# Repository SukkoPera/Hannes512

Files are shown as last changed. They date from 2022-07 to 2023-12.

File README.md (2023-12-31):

# Hannes512
Hannes512 is an Open Hardware internal 512 kB RAM Expansion board for the Commodore 16.

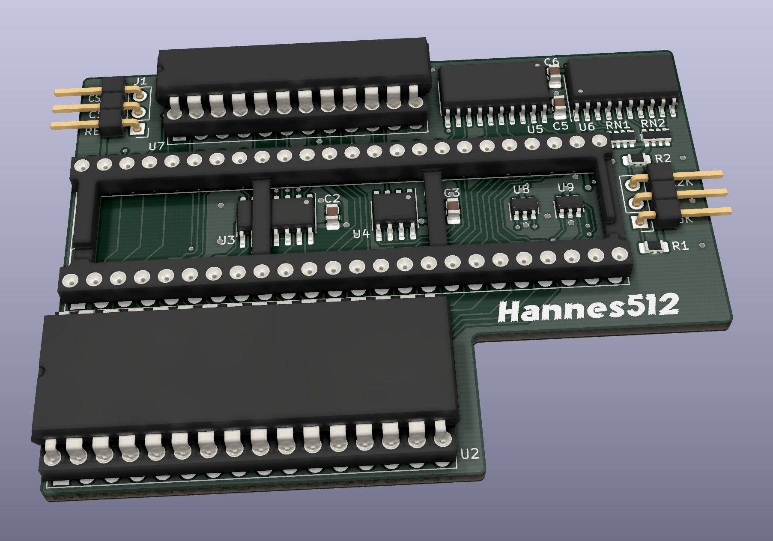
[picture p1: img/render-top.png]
Board


## Summary
While making [Hannes256](https://github.com/SukkoPera/Hannes256) two shortcomings became apparent:
* The RAM chips needed to be recovered from old equipment or bought second-hand
* The power draw was probably pretty significant (although I never measured it)

It was pretty obvious that switching to a modern SRAM would alleviate both issues, so I went looking for modern chips I could use and the Alliance AS6C4008 turned out to be a perfect match. Besides, it is 512 kB so I even went beyond the original goals and made all of that available to the C16 (even though that can create incompatibilities, see below).

## Design and Assembly Notes
This board is basically a variant of [Hannes256](https://github.com/SukkoPera/Hannes256#design-and-assembly-notes), so most of what you can read on that page also applies to this board.

One exception is that I reintroduced the ESD protection diodes for the TED that were featured in [Fixteen](https://github.com/SukkoPera/Fixteen). They are U8 and U9 and they are optional.

### RAM Compatibility
Both AS6C4008-55PCN and -55PIN have been tested and work fine. I don't know about any other chips, but it's possible that other SRAMs will work.

AS6C4008 chips can either be bought new from electronic distributors or (probably-) used from AliExpress. I have bought a few of the latter and they were all working correctly.

## Installation
See [Hannes256](https://github.com/SukkoPera/Hannes256#installation).

## Technical Notes
While the mechanism originally devised by Hannes/Solder for 256 kB memory expansion can easily be extended to 512 kB and even 1 MB expansions, it requires that software programmers behave correctly and consider the *default bank* to be bank 15. Unfortunately, some of the software requiring 256 kB that already exists was written with the assumption that no expansion larger than 256 kB would ever surface and sets bits 2/3 of the expansion control register to 0 when wanting to switch to the default bank.

This problem affects [Dream World](img/dreamworld_fd16_startup.png) and even the modern-era [Lykia](img/lykia_fd16_startup.png), for instance. The only real solution is to patch the software, but until someone does that, another option is to just limit memory expansions to 256 kB. After all, there is no software (... yet!) that needs more than that, so it currently looks like an acceptable compromise.

The great news is that this is rather easy to do in Hannes512, you just need to program the GAL with a different file. The [gal directory](gal/) contains a number of different JED files:
* **Hannes512_GAL2x.jed**: These files provide the full 512 kB.
* **Hanns512_G2x256.jed**: These files are limited to 256 kB and are the **recommended ones** to be used at the time being.
* **Hanns512_G2xH37.jed**: These files feature a hack that tries to provide more than 256 kB of memory while making banks 3 and 7 the same bank; it's a temporary hack I made mainly for myself, so please disregard it.

Feel free to open an issue if you have some suggestions on this topic.

## Testing
See [Hannes256](https://github.com/SukkoPera/Hannes256#testing).

## Programming
See [Hannes256](https://github.com/SukkoPera/Hannes256#programming), but keep in mind what is said in the *Technical Notes* above.

## Releases
If you want to get this board produced, you are recommended to get [the latest release](https://github.com/SukkoPera/Hannes512/releases) rather than the current git version, as the latter might be under development and is not guaranteed to be working.

Every release is accompanied by its Bill Of Materials (BOM) file and any relevant notes about it, which you are recommended to read carefully.

## License
The Hannes512 documentation, including the design itself, is copyright &copy; SukkoPera 2022-2023 and is licensed under the [Creative Commons Attribution-NonCommercial-ShareAlike 4.0 International License](https://creativecommons.org/licenses/by-nc-sa/4.0/).

This documentation is distributed *as is* and WITHOUT ANY EXPRESS OR IMPLIED WARRANTIES whatsoever with respect to its functionality, operability or use, including, without limitation, any implied warranties OF MERCHANTABILITY, SATISFACTORY QUALITY, FITNESS FOR A PARTICULAR PURPOSE or infringement. We expressly disclaim any liability whatsoever for any direct, indirect, consequential, incidental or special damages, including, without limitation, lost revenues, lost profits, losses resulting from business interruption or loss of data, regardless of the form of action or legal theory under which the liability may be asserted, even if advised of the possibility or likelihood of such damages.

## Support the Project
If you want to get some boards manufactured, you can get them from PCBWay through this link:

PCB from PCBWay (https://www.pcbway.com/project/shareproject/Hannes512_512_kB_RAM_Expansion_for_the_Commodore_16_4_e876fa91.html)

You get my gratitude and cheap, professionally-made and good quality PCBs, I get some credit that will help with this and [other projects](https://www.pcbway.com/project/member/?bmbno=72D33927-5EF6-42). You won't even have to worry about the various PCB options, it's all pre-configured for you!

Also, if you still have to register, [you can use this link](https://www.pcbway.com/setinvite.aspx?inviteid=41100) to get some bonus initial credit (and yield me some more).

You can also buy me a coffee if you want:

<a href='https://ko-fi.com/L3L0U18L' target='_blank'>Buy Me a Coffee at ko-fi.com</a>

## Thanks
* Hannes and Solder for the original design and documentation.
* eslapion for the SRAM enable circuit, saving me endless hours of debugging.
* Levente Hársfalvi (TLC) for plenty of help, in particular with the MOS 6529 replacement circuit.
* siz for the memory test utility.
* Alit Design for the [Crotah font](https://www.fontspace.com/crotah-font-f86873) used for the logo.

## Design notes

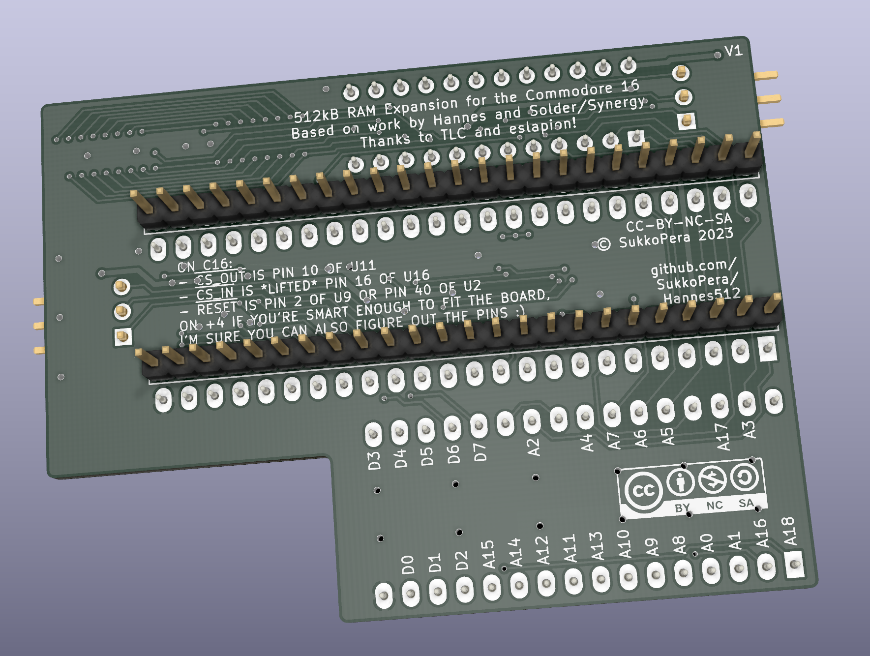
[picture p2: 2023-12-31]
img/render-bottom.png

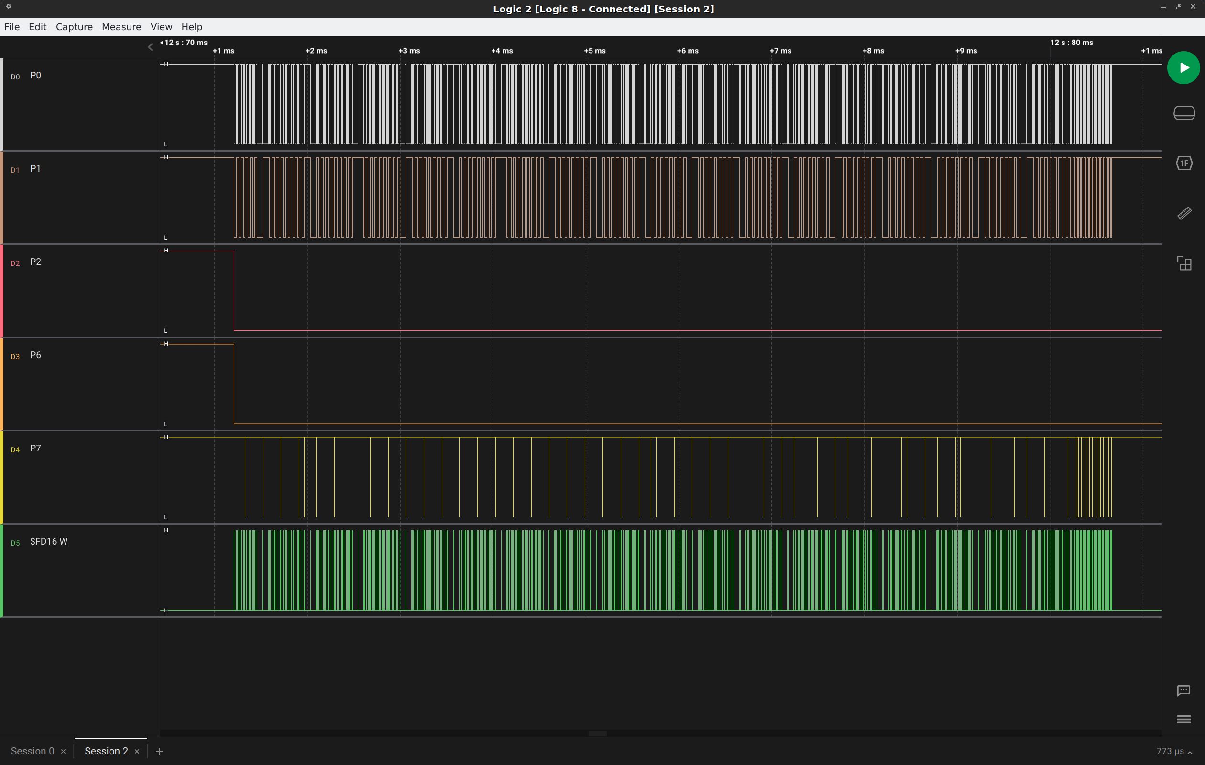
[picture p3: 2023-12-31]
doc/dreamworld_fd16_startup.png

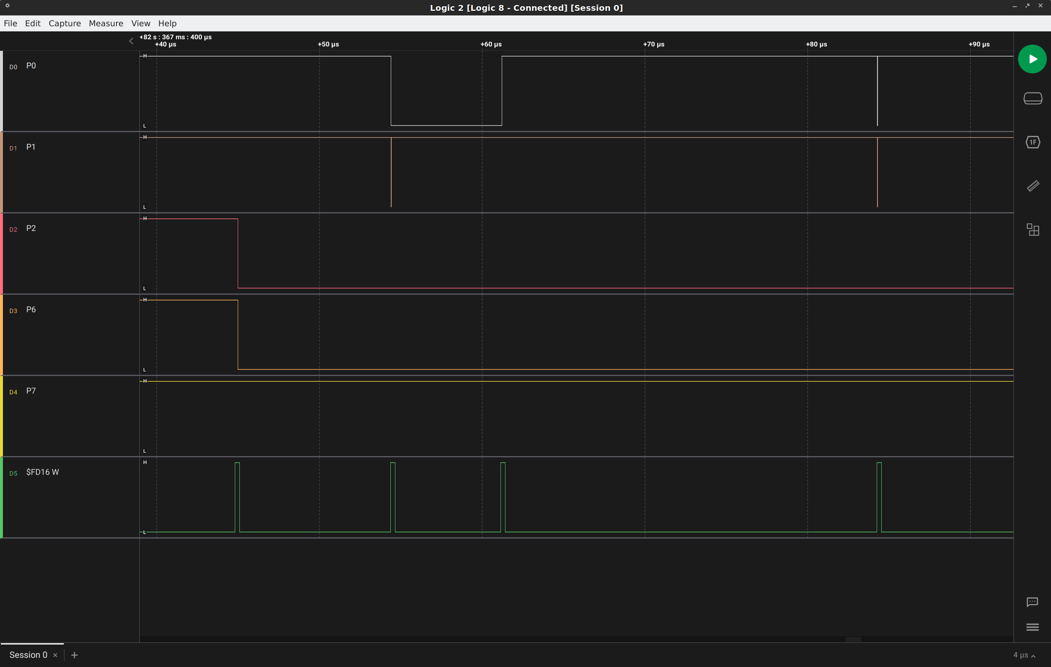
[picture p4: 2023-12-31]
doc/lykia_fd16_startup.png

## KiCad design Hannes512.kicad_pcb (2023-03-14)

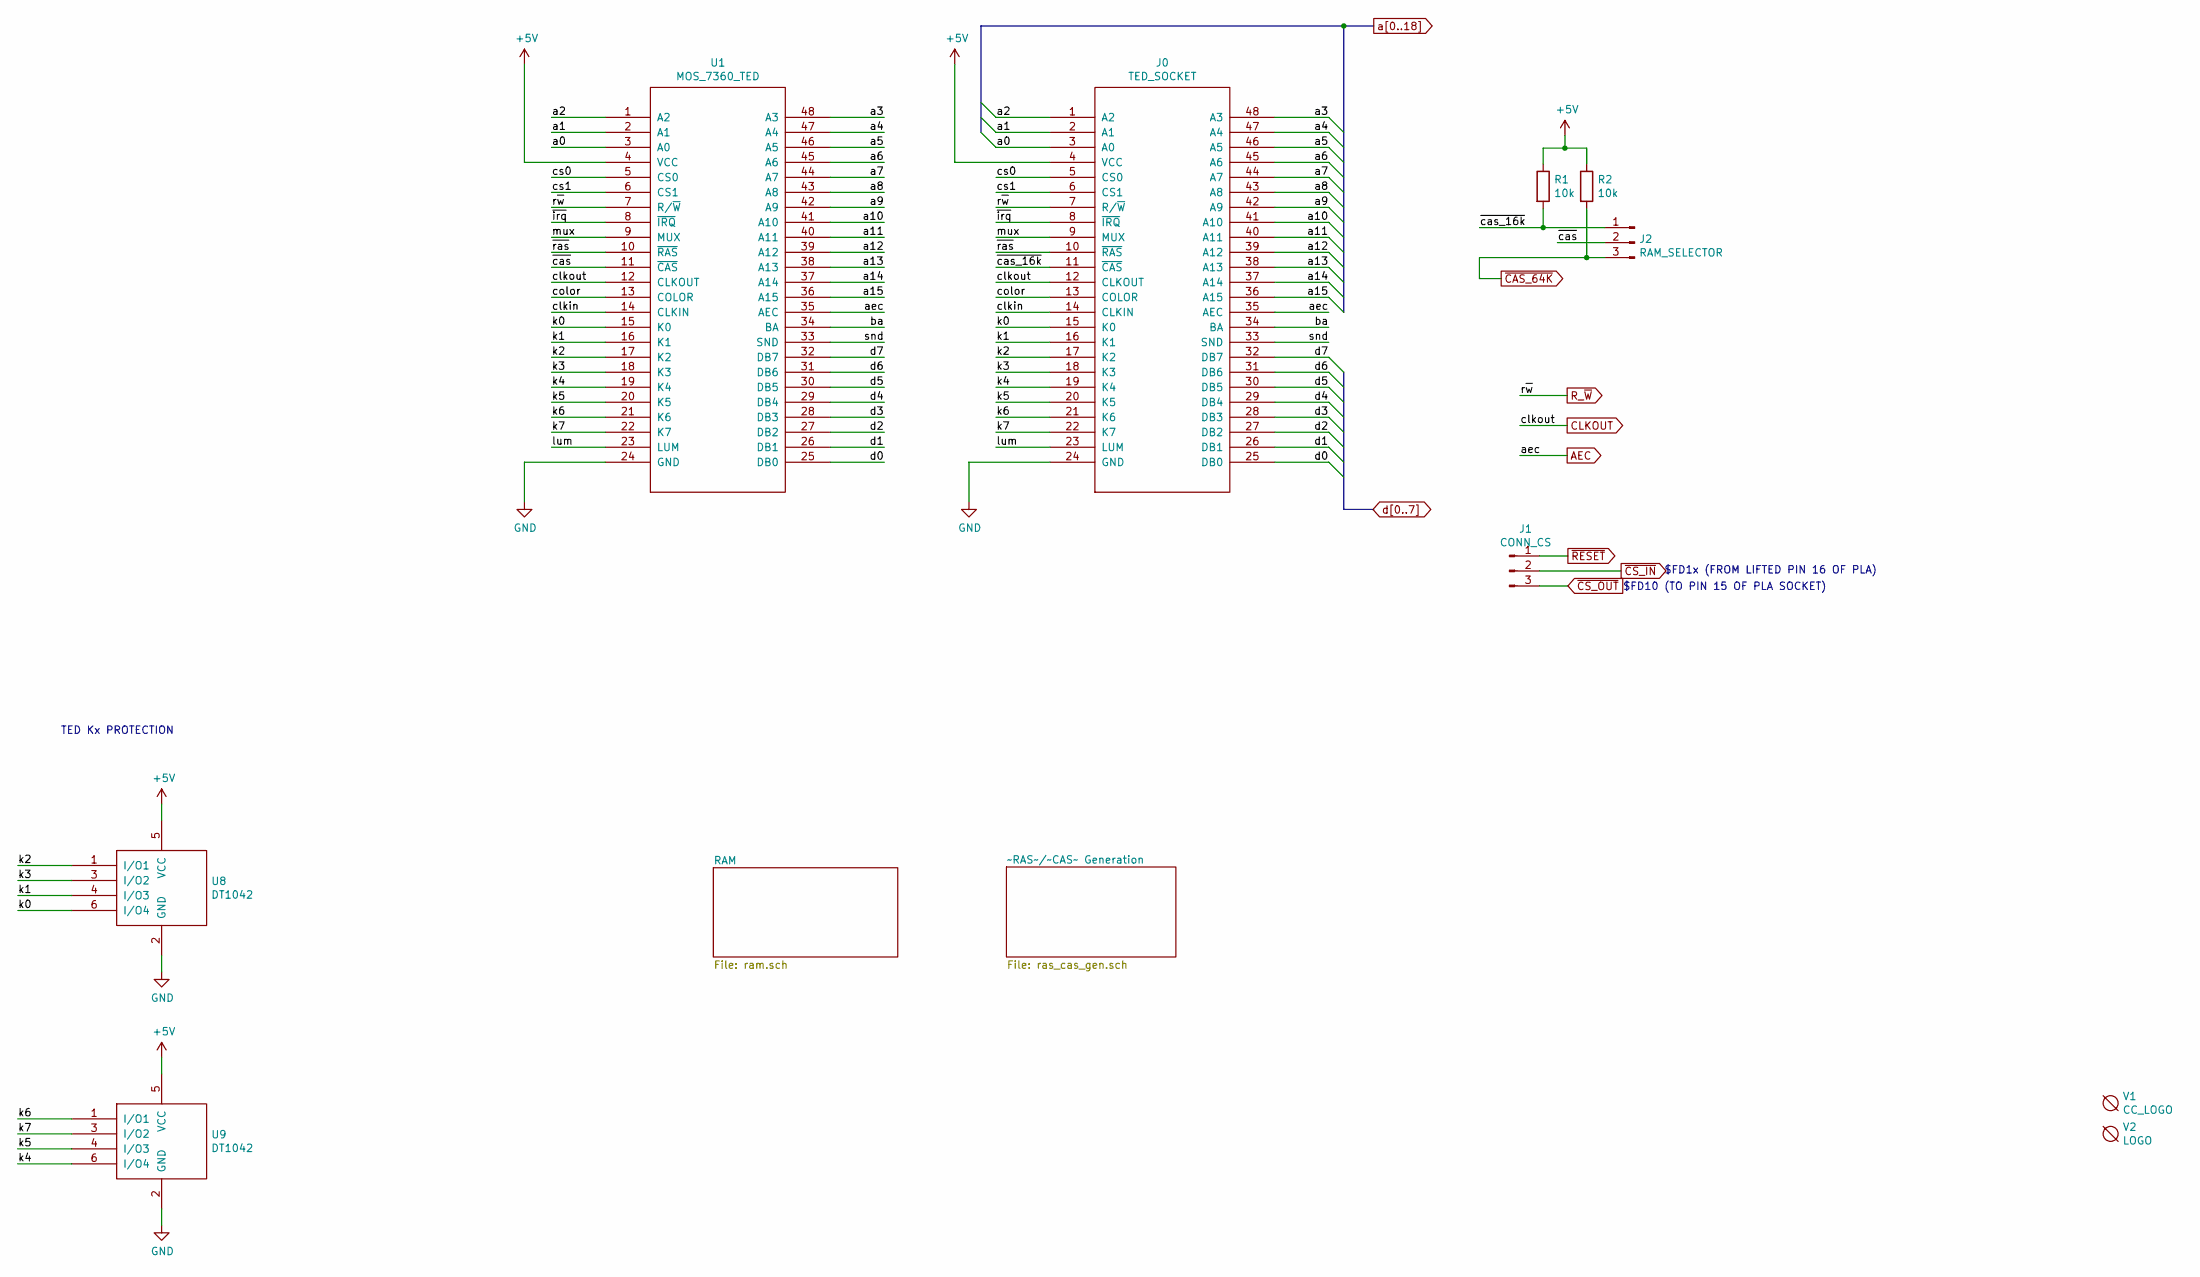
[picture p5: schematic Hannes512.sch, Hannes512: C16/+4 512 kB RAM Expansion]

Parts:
J0: TED_SOCKET; DIP-48_W15.24mm_LongPads_ModSilkS
J1: CONN_CS; PinHeader_1x03_P2.54mm_Vertical
J2: RAM_SELECTOR; PinHeader_1x03_P2.54mm_Vertical
R1, R2: 10k; R_0805_2012Metric_Pad1.20x1.40mm_HandSolder
U1: MOS_7360_TED; DIP-48_W15.24mm_Socket_LongPads
U8, U9: DT1042; TSOP-6_1.65x3.05mm_P0.95mm
V1: CC_LOGO; cc_by_nc_sa
V2: LOGO; logo

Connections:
+5V: J0.4 (VCC), R1.1, R2.1, U1.4 (VCC), U8.5 (VCC), U9.5 (VCC); also elsewhere on the board
/ba: J0.34 (BA), U1.34 (BA)
/clkin: J0.14 (CLKIN), U1.14 (CLKIN)
/color: J0.13 (COLOR), U1.13 (COLOR)
/cs0: J0.5 (CS0), U1.5 (CS0)
/cs1: J0.6 (CS1), U1.6 (CS1)
/k0: J0.15 (K0), U1.15 (K0), U8.6 (I/O4)
/k1: J0.16 (K1), U1.16 (K1), U8.4 (I/O3)
/k2: J0.17 (K2), U1.17 (K2), U8.1 (I/O1)
/k3: J0.18 (K3), U1.18 (K3), U8.3 (I/O2)
/k4: J0.19 (K4), U1.19 (K4), U9.6 (I/O4)
/k5: J0.20 (K5), U1.20 (K5), U9.4 (I/O3)
/k6: J0.21 (K6), U1.21 (K6), U9.1 (I/O1)
/k7: J0.22 (K7), U1.22 (K7), U9.3 (I/O2)
/lum: J0.23 (LUM), U1.23 (LUM)
/mux: J0.9 (MUX), U1.9 (MUX)
/snd: J0.33 (SND), U1.33 (SND)
/~cas: J2.2, U1.11 (~CAS)
/~cas_16k: J0.11 (~CAS), J2.1, R1.2
/~irq: J0.8 (~IRQ), U1.8 (~IRQ)
/~ras: J0.10 (~RAS), U1.10 (~RAS)
AEC: J0.35 (AEC), U1.35 (AEC); also elsewhere on the board
CLKOUT: J0.12 (CLKOUT), U1.12 (CLKOUT); also elsewhere on the board
GND: J0.24 (GND), U1.24 (GND), U8.2 (GND), U9.2 (GND); also elsewhere on the board
R_~W: J0.7 (R/~W), U1.7 (R/~W); also elsewhere on the board
a0: J0.3 (A0), U1.3 (A0); also elsewhere on the board
a1: J0.2 (A1), U1.2 (A1); also elsewhere on the board
a2: J0.1 (A2), U1.1 (A2); also elsewhere on the board
a3: J0.48 (A3), U1.48 (A3); also elsewhere on the board
a4: J0.47 (A4), U1.47 (A4); also elsewhere on the board
a5: J0.46 (A5), U1.46 (A5); also elsewhere on the board
a6: J0.45 (A6), U1.45 (A6); also elsewhere on the board
a7: J0.44 (A7), U1.44 (A7); also elsewhere on the board
a8: J0.43 (A8), U1.43 (A8); also elsewhere on the board
a9: J0.42 (A9), U1.42 (A9); also elsewhere on the board
a10: J0.41 (A10), U1.41 (A10); also elsewhere on the board
a11: J0.40 (A11), U1.40 (A11); also elsewhere on the board
a12: J0.39 (A12), U1.39 (A12); also elsewhere on the board
a13: J0.38 (A13), U1.38 (A13); also elsewhere on the board
a14: J0.37 (A14), U1.37 (A14); also elsewhere on the board
a15: J0.36 (A15), U1.36 (A15); also elsewhere on the board
d0: J0.25 (DB0), U1.25 (DB0); also elsewhere on the board
d1: J0.26 (DB1), U1.26 (DB1); also elsewhere on the board
d2: J0.27 (DB2), U1.27 (DB2); also elsewhere on the board
d3: J0.28 (DB3), U1.28 (DB3); also elsewhere on the board
d4: J0.29 (DB4), U1.29 (DB4); also elsewhere on the board
d5: J0.30 (DB5), U1.30 (DB5); also elsewhere on the board
d6: J0.31 (DB6), U1.31 (DB6); also elsewhere on the board
d7: J0.32 (DB7), U1.32 (DB7); also elsewhere on the board
~CAS_64K: J2.3, R2.2; also elsewhere on the board
~CS_IN: J1.2; also elsewhere on the board
~CS_OUT: J1.3; also elsewhere on the board
~RESET: J1.1; also elsewhere on the board

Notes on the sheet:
$FD1x (FROM LIFTED PIN 16 OF PLA)
$FD10 (TO PIN 15 OF PLA SOCKET)
TED Kx PROTECTION

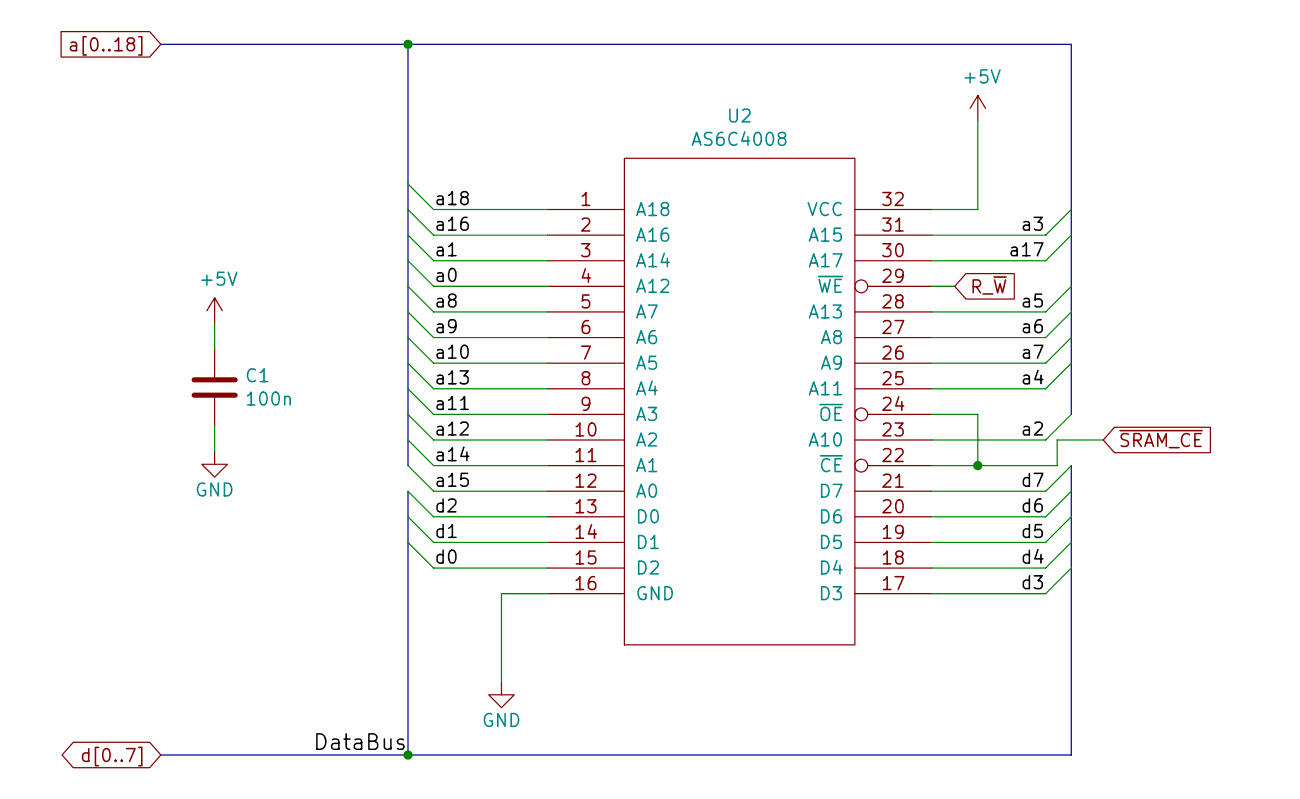
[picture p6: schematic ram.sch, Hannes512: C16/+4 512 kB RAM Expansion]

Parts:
C1: 100n; C_0805_2012Metric_Pad1.18x1.45mm_HandSolder
U2: AS6C4008; DIP-32_W15.24mm_Socket_LongPads

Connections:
+5V: C1.1, U2.32 (VCC); also elsewhere on the board
GND: C1.2, U2.16 (GND); also elsewhere on the board
R_~W: U2.29 (~WE); also elsewhere on the board
a0: U2.4 (A12); also elsewhere on the board
a1: U2.3 (A14); also elsewhere on the board
a2: U2.23 (A10); also elsewhere on the board
a3: U2.31 (A15); also elsewhere on the board
a4: U2.25 (A11); also elsewhere on the board
a5: U2.28 (A13); also elsewhere on the board
a6: U2.27 (A8); also elsewhere on the board
a7: U2.26 (A9); also elsewhere on the board
a8: U2.5 (A7); also elsewhere on the board
a9: U2.6 (A6); also elsewhere on the board
a10: U2.7 (A5); also elsewhere on the board
a11: U2.9 (A3); also elsewhere on the board
a12: U2.10 (A2); also elsewhere on the board
a13: U2.8 (A4); also elsewhere on the board
a14: U2.11 (A1); also elsewhere on the board
a15: U2.12 (A0); also elsewhere on the board
a16: U2.2 (A16); also elsewhere on the board
a17: U2.30 (A17); also elsewhere on the board
a18: U2.1 (A18); also elsewhere on the board
d0: U2.15 (D2); also elsewhere on the board
d1: U2.14 (D1); also elsewhere on the board
d2: U2.13 (D0); also elsewhere on the board
d3: U2.17 (D3); also elsewhere on the board
d4: U2.18 (D4); also elsewhere on the board
d5: U2.19 (D5); also elsewhere on the board
d6: U2.20 (D6); also elsewhere on the board
d7: U2.21 (D7); also elsewhere on the board
~SRAM_CE: U2.22 (~CE), U2.24 (~OE); also elsewhere on the board

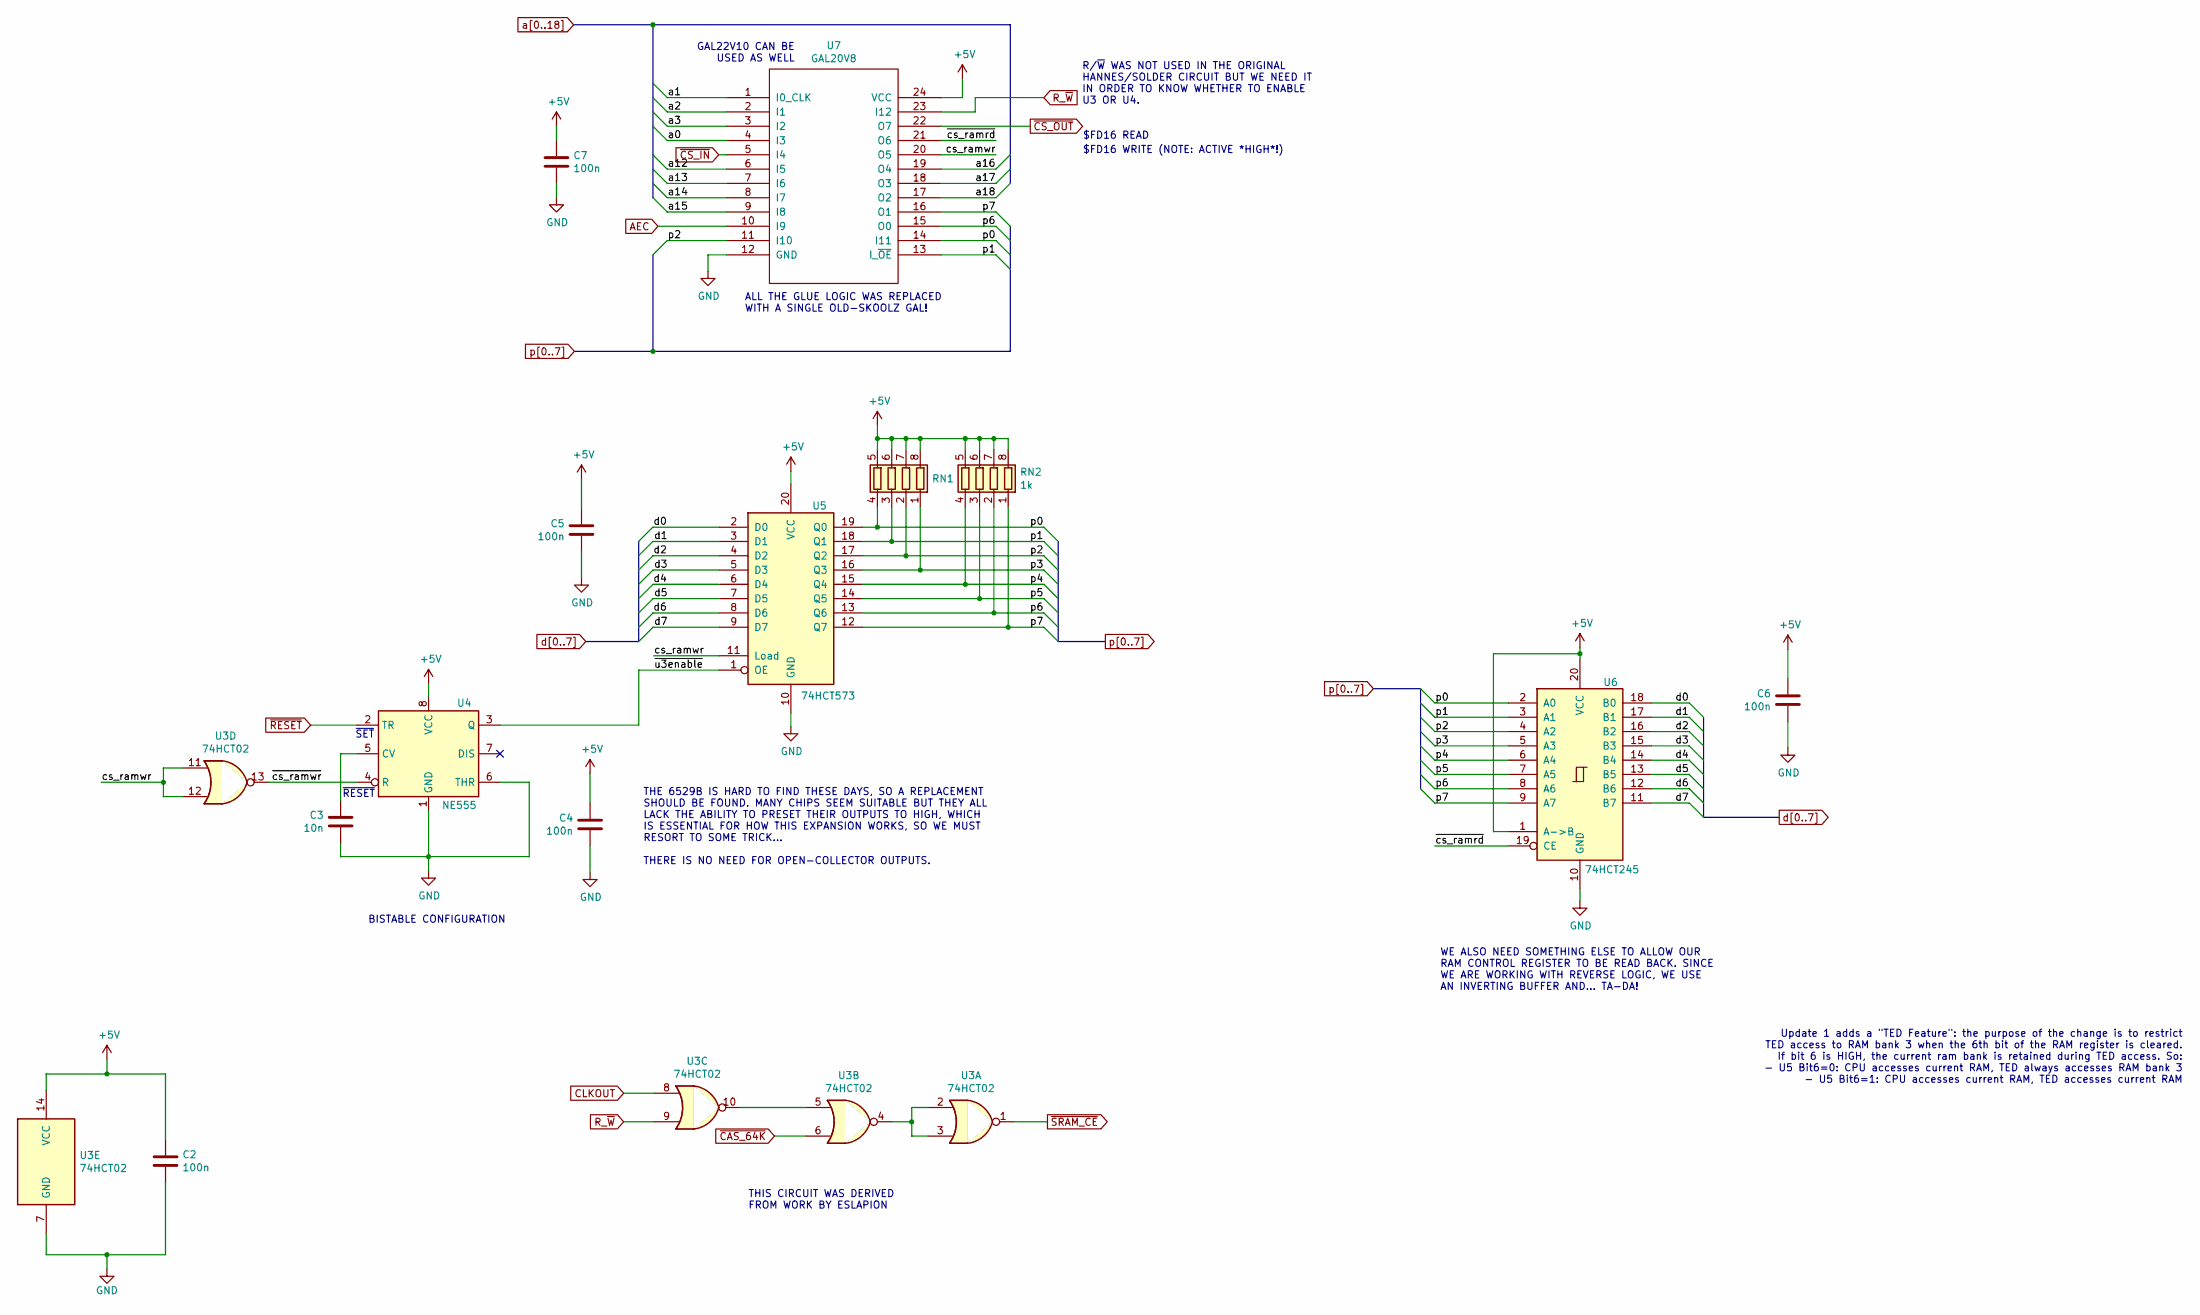
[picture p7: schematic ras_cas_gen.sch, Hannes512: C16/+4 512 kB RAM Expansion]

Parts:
C2, C4, C5, C6, C7: 100n; C_0805_2012Metric_Pad1.18x1.45mm_HandSolder
C3: 10n; C_0805_2012Metric_Pad1.18x1.45mm_HandSolder
RN1, RN2: 1k; R_Array_Convex_4x0603
U3: 74HCT02; SOIC-14_3.9x8.7mm_P1.27mm
U4: NE555; SOIC-8_3.9x4.9mm_P1.27mm
U5: 74HCT573; SO-20_5.3x12.6mm_P1.27mm; MouserPN 595-SN74HCT573NSR
U6: 74HCT245; SO-20_5.3x12.6mm_P1.27mm; MouserPN 595-SN74HCT245ANSR
U7: GAL20V8; DIP-24_W7.62mm_Socket

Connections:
+5V: C2.1, C4.1, C5.1, C6.1, C7.1, RN1.5 (R4.2), RN1.6 (R3.2), RN1.7 (R2.2), RN1.8 (R1.2), RN2.5 (R4.2), RN2.6 (R3.2), RN2.7 (R2.2), RN2.8 (R1.2), U3.14 (VCC), U4.8 (VCC), U5.20 (VCC), U6.1 (A->B), U6.20 (VCC), U7.24 (VCC); also elsewhere on the board
/~RAS~/~CAS~ Generation/cs_ramwr: U3.11, U3.12, U5.11 (Load), U7.20 (O5)
/~RAS~/~CAS~ Generation/~cs_ramrd: U6.19 (CE), U7.21 (O6)
/~RAS~/~CAS~ Generation/~cs_ramwr: U3.13, U4.4 (R)
/~RAS~/~CAS~ Generation/~u3enable: U4.3 (Q), U5.1 (OE)
AEC: U7.10 (I9); also elsewhere on the board
CLKOUT: U3.8; also elsewhere on the board
GND: C2.2, C3.2, C4.2, C5.2, C6.2, C7.2, U3.7 (GND), U4.1 (GND), U4.6 (THR), U5.10 (GND), U6.10 (GND), U7.12 (GND); also elsewhere on the board
unnamed: C3.1, U4.5 (CV)
unnamed: U3.2, U3.3, U3.4
unnamed: U3.5, U3.10
R_~W: U3.9, U7.23 (I12); also elsewhere on the board
a0: U7.4 (I3); also elsewhere on the board
a1: U7.1 (I0_CLK); also elsewhere on the board
a2: U7.2 (I1); also elsewhere on the board
a3: U7.3 (I2); also elsewhere on the board
a12: U7.6 (I5); also elsewhere on the board
a13: U7.7 (I6); also elsewhere on the board
a14: U7.8 (I7); also elsewhere on the board
a15: U7.9 (I8); also elsewhere on the board
a16: U7.19 (O4); also elsewhere on the board
a17: U7.18 (O3); also elsewhere on the board
a18: U7.17 (O2); also elsewhere on the board
d0: U5.2 (D0), U6.18 (B0); also elsewhere on the board
d1: U5.3 (D1), U6.17 (B1); also elsewhere on the board
d2: U5.4 (D2), U6.16 (B2); also elsewhere on the board
d3: U5.5 (D3), U6.15 (B3); also elsewhere on the board
d4: U5.6 (D4), U6.14 (B4); also elsewhere on the board
d5: U5.7 (D5), U6.13 (B5); also elsewhere on the board
d6: U5.8 (D6), U6.12 (B6); also elsewhere on the board
d7: U5.9 (D7), U6.11 (B7); also elsewhere on the board
p0: RN1.4 (R4.1), U5.19 (Q0), U6.2 (A0), U7.14 (I11)
p1: RN1.3 (R3.1), U5.18 (Q1), U6.3 (A1), U7.13 (I_~OE)
p2: RN1.2 (R2.1), U5.17 (Q2), U6.4 (A2), U7.11 (I10)
p3: RN1.1 (R1.1), U5.16 (Q3), U6.5 (A3)
p4: RN2.4 (R4.1), U5.15 (Q4), U6.6 (A4)
p5: RN2.3 (R3.1), U5.14 (Q5), U6.7 (A5)
p6: RN2.2 (R2.1), U5.13 (Q6), U6.8 (A6), U7.15 (O0)
p7: RN2.1 (R1.1), U5.12 (Q7), U6.9 (A7), U7.16 (O1)
~CAS_64K: U3.6; also elsewhere on the board
~CS_IN: U7.5 (I4); also elsewhere on the board
~CS_OUT: U7.22 (O7); also elsewhere on the board
~RESET: U4.2 (TR); also elsewhere on the board
~SRAM_CE: U3.1; also elsewhere on the board

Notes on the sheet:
Update 1 adds a "TED Feature": the purpose of the change is to restrict TED access to RAM bank 3 when the 6th bit of the RAM register is cleared. If bit 6 is HIGH, the current ram bank is retained during TED access. So: - U5 Bit6=0: CPU accesses current RAM, TED always accesses RAM bank 3 - U5 Bit6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
THE 6529B IS HARD TO FIND THESE DAYS, SO A REPLACEMENT SHOULD BE FOUND. MANY CHIPS SEEM SUITABLE BUT THEY ALL LACK THE ABILITY TO PRESET THEIR OUTPUTS TO HIGH, WHICH IS ESSENTIAL FOR HOW THIS EXPANSION WORKS, SO WE MUST RESORT TO SOME TRICK... THERE IS NO NEED FOR OPEN-COLLECTOR OUTPUTS.
ALL THE GLUE LOGIC WAS REPLACED WITH A SINGLE OLD-SKOOLZ GAL!
WE ALSO NEED SOMETHING ELSE TO ALLOW OUR RAM CONTROL REGISTER TO BE READ BACK. SINCE WE ARE WORKING WITH REVERSE LOGIC, WE USE AN INVERTING BUFFER AND... TA-DA!
GAL22V10 CAN BE USED AS WELL
$FD16 READ
~SET
~RESET
BISTABLE CONFIGURATION
R/~W~ WAS NOT USED IN THE ORIGINAL HANNES/SOLDER CIRCUIT BUT WE NEED IT IN ORDER TO KNOW WHETHER TO ENABLE U3 OR U4.
THIS CIRCUIT WAS DERIVED FROM WORK BY ESLAPION
$FD16 WRITE (NOTE: ACTIVE *HIGH*!)

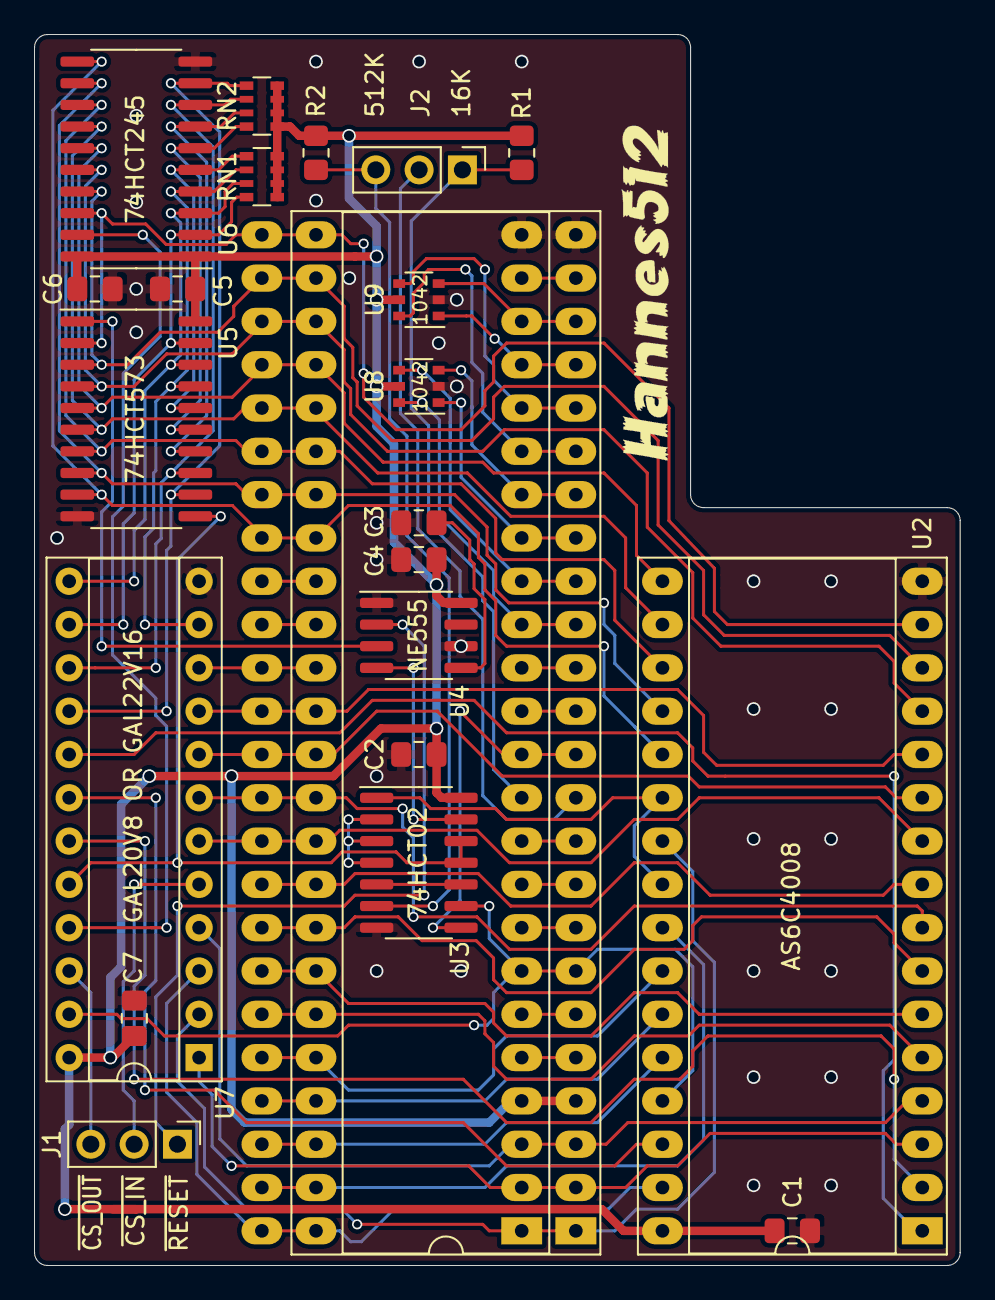
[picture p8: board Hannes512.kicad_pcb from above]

Board: 2 copper layers, 54.3 x 72.2 mm, 25 parts (1 on the bottom side), 72 nets.

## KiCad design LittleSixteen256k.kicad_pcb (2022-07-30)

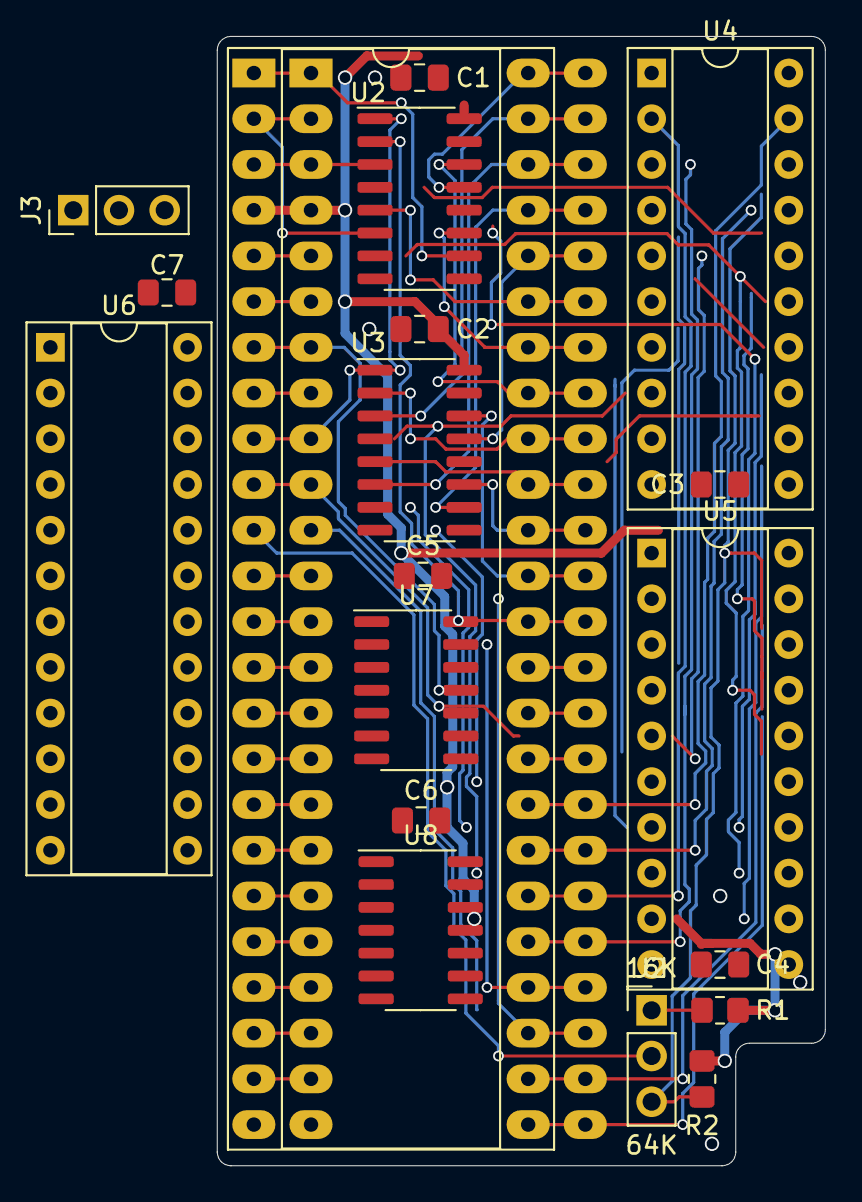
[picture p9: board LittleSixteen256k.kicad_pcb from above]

Board: 2 copper layers, 33.8 x 62.7 mm, 20 parts (0 on the bottom side), 68 nets.

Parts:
C1, C2, C3, C4, C5, C6, C7: 100n; C_0805_2012Metric_Pad1.18x1.45mm_HandSolder
J1: TED_SOCKET; DIP-48_W15.24mm_LongPads_ModSilkS
J2: RAM_SELECTOR; PinHeader_1x03_P2.54mm_Vertical
J3: CONN_CS; PinHeader_1x03_P2.54mm_Vertical
R1, R2: 10k; R_0805_2012Metric_Pad1.20x1.40mm_HandSolder
U1: MOS_7360_TED; DIP-48_W15.24mm_Socket_LongPads
U2, U3: 74LS257; SOIC-16_3.9x9.9mm_P1.27mm
U4, U5: XX4256; DIP-20_W7.62mm_Socket
U6: GAL20V8; DIP-24_W7.62mm_Socket
U7, U8: 74HCT74; SOIC-14_3.9x8.7mm_P1.27mm

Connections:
+5V: C1.1, C3.1, C4.1, C5.1, C6.1, U4.10, U5.10, U6.24, U7.1, U7.13, U7.14, U8.1, U8.13, U8.14
/ba: J1.34, U1.34
/clkin: J1.14, U1.14
/clkout: J1.12, U1.12
/color: J1.13, U1.13
/cs0: J1.5, U1.5
/cs1: J1.6, U1.6
/k0: J1.15, U1.15
/k1: J1.16, U1.16
/k2: J1.17, U1.17
/k3: J1.18, U1.18
/k4: J1.19, U1.19
/k5: J1.20, U1.20
/k6: J1.21, U1.21
/k7: J1.22, U1.22
/lum: J1.23, U1.23
/snd: J1.33, U1.33
/~RAS~/~CAS~ Generation/~cs_ram: U6.22, U7.3, U7.11, U8.3, U8.11
/~cas: J2.2, U1.11
/~cas_16k: J1.11, J2.1, R1.2
/~irq: J1.8, U1.8
AEC: J1.35, U1.35, U6.16
GND: C1.2, C2.2, C3.2, C4.2, C5.2, C6.2, C7.2, J1.24, U1.24, U2.8, U2.15, U3.8, U3.15, U4.16, U4.20, U5.16, U5.20, U6.12, U7.7, U8.7
MUX: J1.9, U1.9, U2.1, U3.1, U6.10
unnamed: U6.11, U7.5
unnamed: U6.13, U7.9
unnamed: U6.14, U8.5
unnamed: U6.15, U8.9
R_~W: J1.7, U1.7, U4.3, U5.3
VCC: C2.1, C7.1, J1.4, R1.1, R2.1, U1.4, U2.16, U3.16
a0: J1.3, U1.3, U2.3, U6.1, U6.6
a1: J1.2, U1.2, U2.6, U6.2, U6.7
a2: J1.1, U1.1, U2.10, U6.3, U6.8
a3: J1.48, U1.48, U2.13, U6.4, U6.9
a4: J1.47, U1.47, U3.3
a5: J1.46, U1.46, U3.6
a6: J1.45, U1.45, U3.10
a7: J1.44, U1.44, U3.13
a8: J1.43, U1.43, U2.5
a9: J1.42, U1.42, U2.11
a10: J1.41, U1.41, U2.14
a11: J1.40, U1.40, U3.2
a12: J1.39, U1.39, U3.5
a13: J1.38, U1.38, U3.11
a14: J1.37, U1.37, U3.14
a15: J1.36, U1.36, U2.2
d0: J1.25, U1.25, U5.1, U7.2
d1: J1.26, U1.26, U5.2, U7.12
d2: J1.27, U1.27, U5.18
d3: J1.28, U1.28, U5.19
d4: J1.29, U1.29, U4.1
d5: J1.30, U1.30, U4.2
d6: J1.31, U1.31, U4.18, U8.2
d7: J1.32, U1.32, U4.19, U8.12
m0: U2.4, U4.6, U5.6
m1: U2.7, U4.7, U5.7
m2: U2.9, U4.8, U5.8
m3: U2.12, U4.9, U5.9
m4: U3.4, U4.11, U5.11
m5: U3.7, U4.12, U5.12
m6: U3.9, U4.13, U5.13
m7: U3.12, U4.14, U5.14
m8: U4.15, U5.15, U6.20
~CAS_64K: J2.3, R2.2, U4.17, U5.17
~CS_IN: J3.2, U6.5
~CS_OUT: J3.3, U6.21
~RAS: J1.10, U1.10, U4.4, U5.4
~RESET: J3.1, U7.4, U7.10, U8.4, U8.10

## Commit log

2022-07-26 Initial dsegin, should match Hannes's
    [LittleSixteen256k.kicad_pcb, LittleSixteen256k.sch]
2022-07-26 Add decoupling caps
    [LittleSixteen256k.sch]
2022-07-26 Apply "Update 1" introducing the "TED Feature" Restricts TED access to RAM bank 3 when the 6th bit of the RAM register is cleared.
    [LittleSixteen256k.sch]
2022-07-29 Hopefully we now have the schematics for a fully working internal RAM expansion
    [LittleSixteen256k.sch, ram.sch, ras_cas_gen.sch]
2022-07-29 Switch out the MOS 6529
    [LittleSixteen256k.sch, ram.sch, ras_cas_gen.sch]
2022-07-29 Switch all glue logic to a GAL
    [ras_cas_gen.sch]
2022-07-30 Start working on PCB
    [LittleSixteen256k.kicad_pcb, LittleSixteen256k.sch, ram.sch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]
2022-08-16 Fix address pins
    [ras_cas_gen.sch]
2022-09-19 LittleSixteen256k -> Hannes256
    [Hannes256.kicad_pcb, Hannes256.sch, ram.sch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]
2022-09-19 Routing in progress
    [Hannes256.kicad_pcb, Hannes256.sch, ras_cas_gen.sch]
2022-09-25 Switch to 41256 RAM This will handle the refresh properly despite needing 8 chips instead of 2, sigh...
    [Hannes256.kicad_pcb, Hannes256.sch, ram.sch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]
2022-09-25 Routing almost done
    [Hannes256.kicad_pcb]
2022-09-26 Initial routing complete
    [Hannes256.kicad_pcb]
2022-09-26 Yeah yeah yeah
    [Hannes256.kicad_pcb, ras_cas_gen.sch]
2022-09-26 Add credits
    [Hannes256.kicad_pcb, Hannes256.sch, ram.sch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]
2022-09-26 Add logo and ready for V1rc1
    [Hannes256.kicad_pcb, Hannes256.sch, ras_cas_gen.sch]
2022-10-08 Cosmetic fixes
    [Hannes256.kicad_pcb]
2022-10-25 Bring R/W to the GAL We'll have to write an essay on this...
    [Hannes256.kicad_pcb, Hannes256.sch, ram.sch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]
2022-10-25 Center C13 within U13 The socket won't fit otherwise!
    [Hannes256.kicad_pcb]
2022-10-29 Add a 74x245 to provide RAM register read functionality
    [ras_cas_gen.sch]
2022-12-08 Use a different MOS 6529 replacement circuit, courtesy of TLC
    [Hannes256.kicad_pcb, Hannes256.sch, ras_cas_gen.sch]
2022-12-11 Update silkscreen
    [Hannes256.kicad_pcb, ras_cas_gen.sch]
2023-01-09 Fix U3 Latch Enable, sigh... GAL equations TBD
    [Hannes256.kicad_pcb, ras_cas_gen.sch]
2023-02-15 Use bank 3 when in non-switchable range *Maybe* this only reshuffles the banks around, but anyway it results in simplified equations that let us avoid using an intermediate signal, freeing one pin - 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
2023-02-22 More routing
    [Hannes256.kicad_pcb, ram.sch]
2023-02-26 ROuting done
    [Hannes256.kicad_pcb, Hannes256.sch, ram.sch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]
2023-02-27 Relabel all components
    [Hannes256.kicad_pcb, Hannes256.sch, ram.sch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]
2023-02-27 Hannes256 -> Hannes512
    [Hannes512.kicad_pcb, Hannes512.sch, ram.sch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]
2023-02-27 Ready for V1
    [Hannes512.kicad_pcb, ras_cas_gen.sch]
2023-02-27 Some rerouting
    [Hannes512.kicad_pcb]
2023-02-27 More rerouting
    [Hannes512.kicad_pcb, ram.sch, ras_cas_gen.sch]
2023-02-28 Relocate RN1/2 on top
    [Hannes512.kicad_pcb]
2023-03-14 Add TED Kx Protection
    [Hannes512.kicad_pcb, Hannes512.sch, ram.sch]
2023-03-14 Ground plane improvements
    [Hannes512.kicad_pcb]
2023-12-29 Add part numbers
    [Hannes512.sch, ram.sch, ras_cas_gen.sch]
2023-12-31 Update board link

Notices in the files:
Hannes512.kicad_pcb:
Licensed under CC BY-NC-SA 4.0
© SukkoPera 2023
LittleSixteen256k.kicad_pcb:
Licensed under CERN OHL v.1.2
